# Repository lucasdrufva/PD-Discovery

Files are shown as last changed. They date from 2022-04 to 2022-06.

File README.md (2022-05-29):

# PD-Discovery

<div>
  <p align="center">
     
  </p>
</div>

A tool for analyzing and discovering the Power Delivery Protocol for USB-C

[Demo Video](https://youtu.be/lnGGlh1nLXM)

<p float="left">
  
   
</p>

Capable of 
 - Requesting identity from electronically marked cables, displaying supported Amp rating and length of cable
 - Displaying source capabilities including the different voltage and current ratings
 - Requesting power from a source and providing it on a screw terminal 
 - Displaying sink capabilities including the different voltage and current ratings
 - Providing power from internal battery to answer source request
 - Charge internal battery by requesting 5 Volt

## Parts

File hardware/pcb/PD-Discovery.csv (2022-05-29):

Reference | Quantity | Value | Footprint | Datasheet | MANUFACTURER | MAXIMUM_PACKAGE_HEIGHT | PARTREV | STANDARD
B1 | 1 | SSSS810701 | SSSS810701:SSSS810701
C11 C12 | 2 | 16pF | Capacitor_SMD:C_0603_1608Metric | ~
C13 | 1 | 1uF | Capacitor_SMD:C_0805_2012Metric | ~
C2 C5 C14 C15 C19 | 5 | 10uF | Capacitor_SMD:C_0603_1608Metric | ~
C20 C21 | 2 | 4.7uF | Capacitor_SMD:C_0603_1608Metric | ~
C4 C6 | 2 | 470pF | Capacitor_SMD:C_0603_1608Metric | ~
C1 C3 C7 C17 C18 | 5 | 0.1uF | Capacitor_SMD:C_0603_1608Metric | ~
C8 C9 C10 C16 | 4 | 22uF | Capacitor_SMD:C_0805_2012Metric | ~
D3 D5 | 2 | D_Schottky | digikey-footprints:DO-214AC | ~
D4 | 1 | LED | LED_SMD:LED_1206_3216Metric | ~
J1 | 1 | USB_C_Receptacle | Connector_USB:USB_C_Receptacle_Amphenol_12401610E4-2A | https://www.usb.org/sites/default/files/documents/usb_type-c.zip
J2 | 1 | Battery | Connector_JST:JST_PH_S2B-PH-K_1x02_P2.00mm_Horizontal | ~
J3 | 1 | SWD | Connector_PinHeader_2.54mm:PinHeader_1x04_P2.54mm_Vertical | ~
J4 | 1 | ScrewTerminal | 2pScrewTerminal:691214110002
J5 | 1 | DisplayFPC | ER-CON24HT:ER-CON24HT-1
L1 L2 | 2 | 22uH | Inductor_SMD:L_Sumida_CDMC6D28_7.25x6.5mm | ~
Q1 Q4 | 2 | AO3401A | Package_TO_SOT_SMD:SOT-23 | http://www.aosmd.com/pdfs/datasheet/AO3401A.pdf
Q2 Q3 Q5 Q6 | 4 | BC817 | Package_TO_SOT_SMD:SOT-23 | https://www.onsemi.com/pub/Collateral/BC818-D.pdf
Q7 | 1 | FS8205 | FS8205:SOT95P280X145-6N |  | Fortune | 1.45mm | 1.9 | IPC-7351B
R2 R10 | 2 | 1M | Resistor_SMD:R_0805_2012Metric | ~
R11 | 1 | 150K | Resistor_SMD:R_0805_2012Metric | ~
R12 | 1 | 100 | Resistor_SMD:R_0805_2012Metric | ~
R13 | 1 | 7.5K | Resistor_SMD:R_0805_2012Metric | ~
R16 | 1 | 1.35K | Resistor_SMD:R_0603_1608Metric | ~
R1 R15 R18 R21 R26 R27 R29 R30 R31 R32 R33 R34 | 12 | 10K | Resistor_SMD:R_0603_1608Metric | ~
R19 | 1 | 220 | Resistor_SMD:R_1206_3216Metric | ~
R22 | 1 | 1.5K | Resistor_SMD:R_0603_1608Metric | ~
R24 | 1 | 2K | Resistor_SMD:R_0603_1608Metric | ~
R28 | 1 | 900K | Resistor_SMD:R_0603_1608Metric | ~
R3 | 1 | 523K | Resistor_SMD:R_0603_1608Metric | ~
R4 R20 R23 R25 | 4 | 5K | Resistor_SMD:R_0603_1608Metric | ~
R5 R6 R7 | 3 | 4.7K | Resistor_SMD:R_0603_1608Metric | ~
R8 | 1 | 3K | Resistor_SMD:R_0805_2012Metric | ~
R9 R14 R17 | 3 | 1K | Resistor_SMD:R_0805_2012Metric | ~
S1 | 1 | SLLB120300 | SLLB120300:SW_SLLB120300 |  | ALPS | 3.5 mm |  | Manufacturer recommendations
SW3 | 1 | SW_Push | Button_Switch_SMD:SW_Push_1P1T_NO_6x6mm_H9.5mm | ~
U1 | 1 | TP4056 | TP40:SOIC127P600X175-9N
U2 | 1 | FUSB302BMPX | Package_DFN_QFN:WQFN-14-1EP_2.5x2.5mm_P0.5mm_EP1.45x1.45mm | http://www.onsemi.com/pub/Collateral/FUSB302B-D.PDF
U3 | 1 | DW01 | Package_TO_SOT_SMD:SOT-23-6
U4 U5 | 2 | MT3608 | Package_TO_SOT_SMD:SOT-23-6 | https://www.olimex.com/Products/Breadboarding/BB-PWR-3608/resources/MT3608.pdf
U6 | 1 | AMS1117-3.3 | Package_TO_SOT_SMD:SOT-223-3_TabPin2 | http://www.advanced-monolithic.com/pdf/ds1117.pdf
U7 | 1 | ATSAMD21E18A-A | Package_QFP:TQFP-32_7x7mm_P0.8mm | http://ww1.microchip.com/downloads/en/DeviceDoc/SAM_D21_DA1_Family_Data%20Sheet_DS40001882E.pdf
Y1 | 1 | Crystal | Crystal:Crystal_SMD_3215-2Pin_3.2x1.5mm | ~

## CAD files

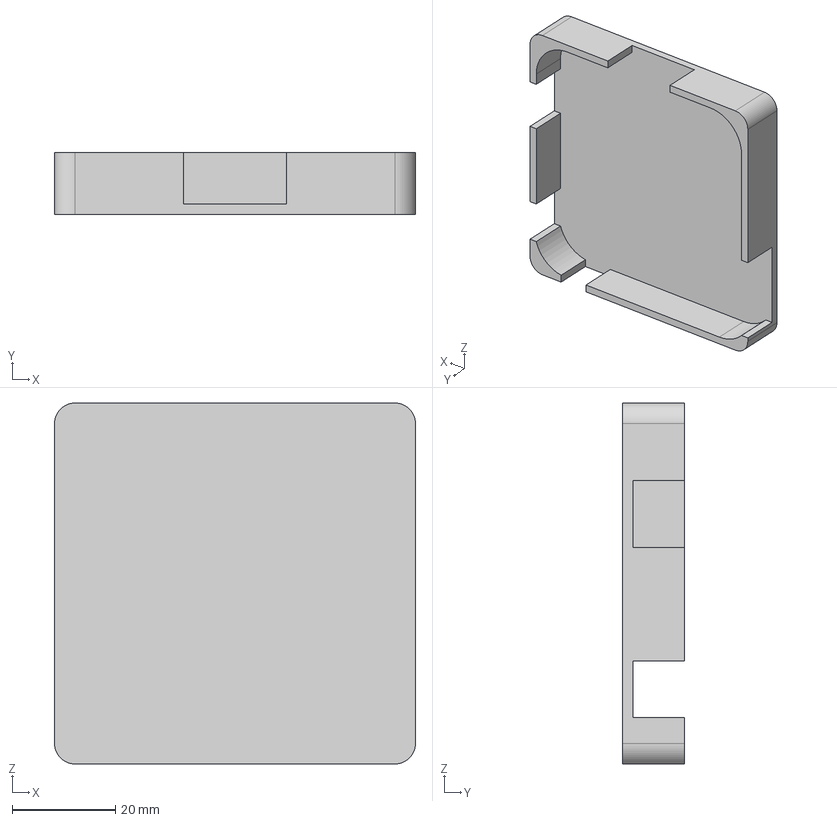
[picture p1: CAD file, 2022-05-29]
hardware/backpanel.step
70.0 x 12.0 x 70.0 mm

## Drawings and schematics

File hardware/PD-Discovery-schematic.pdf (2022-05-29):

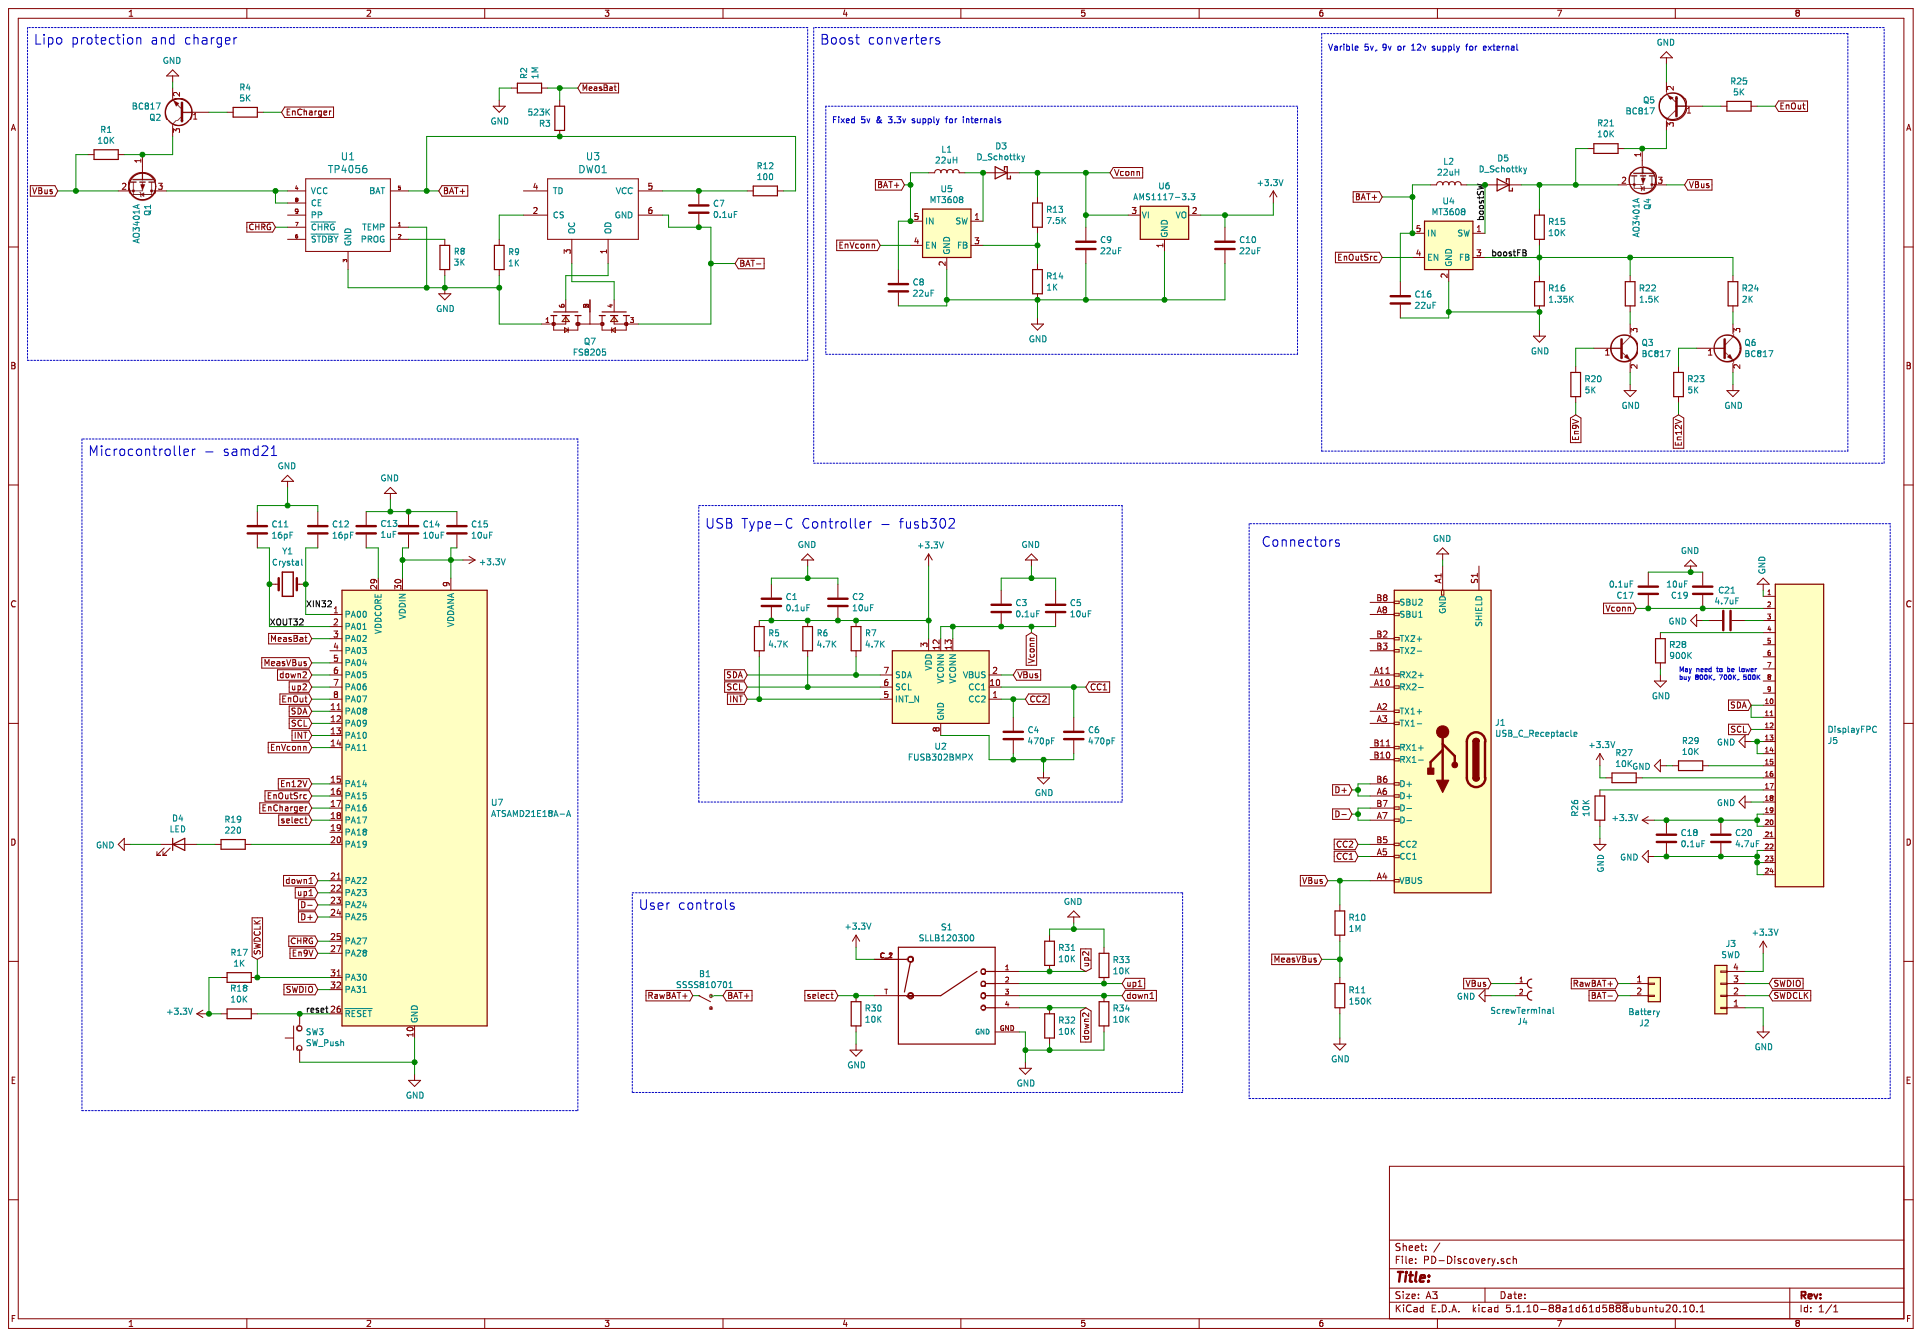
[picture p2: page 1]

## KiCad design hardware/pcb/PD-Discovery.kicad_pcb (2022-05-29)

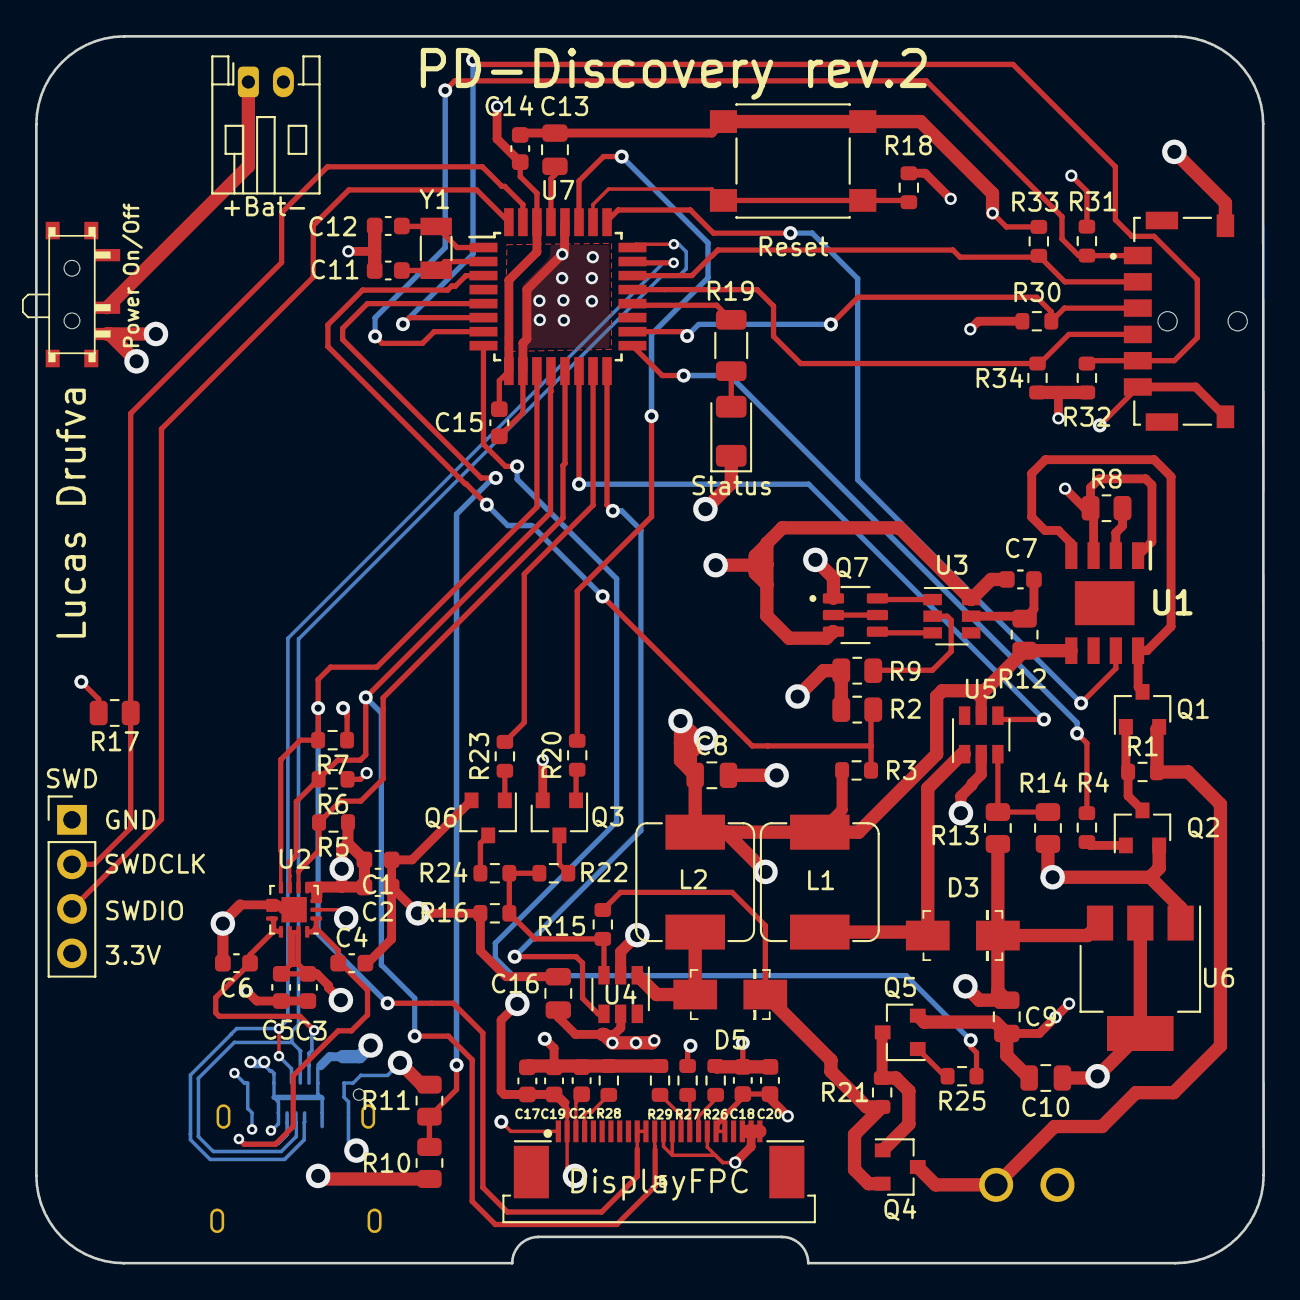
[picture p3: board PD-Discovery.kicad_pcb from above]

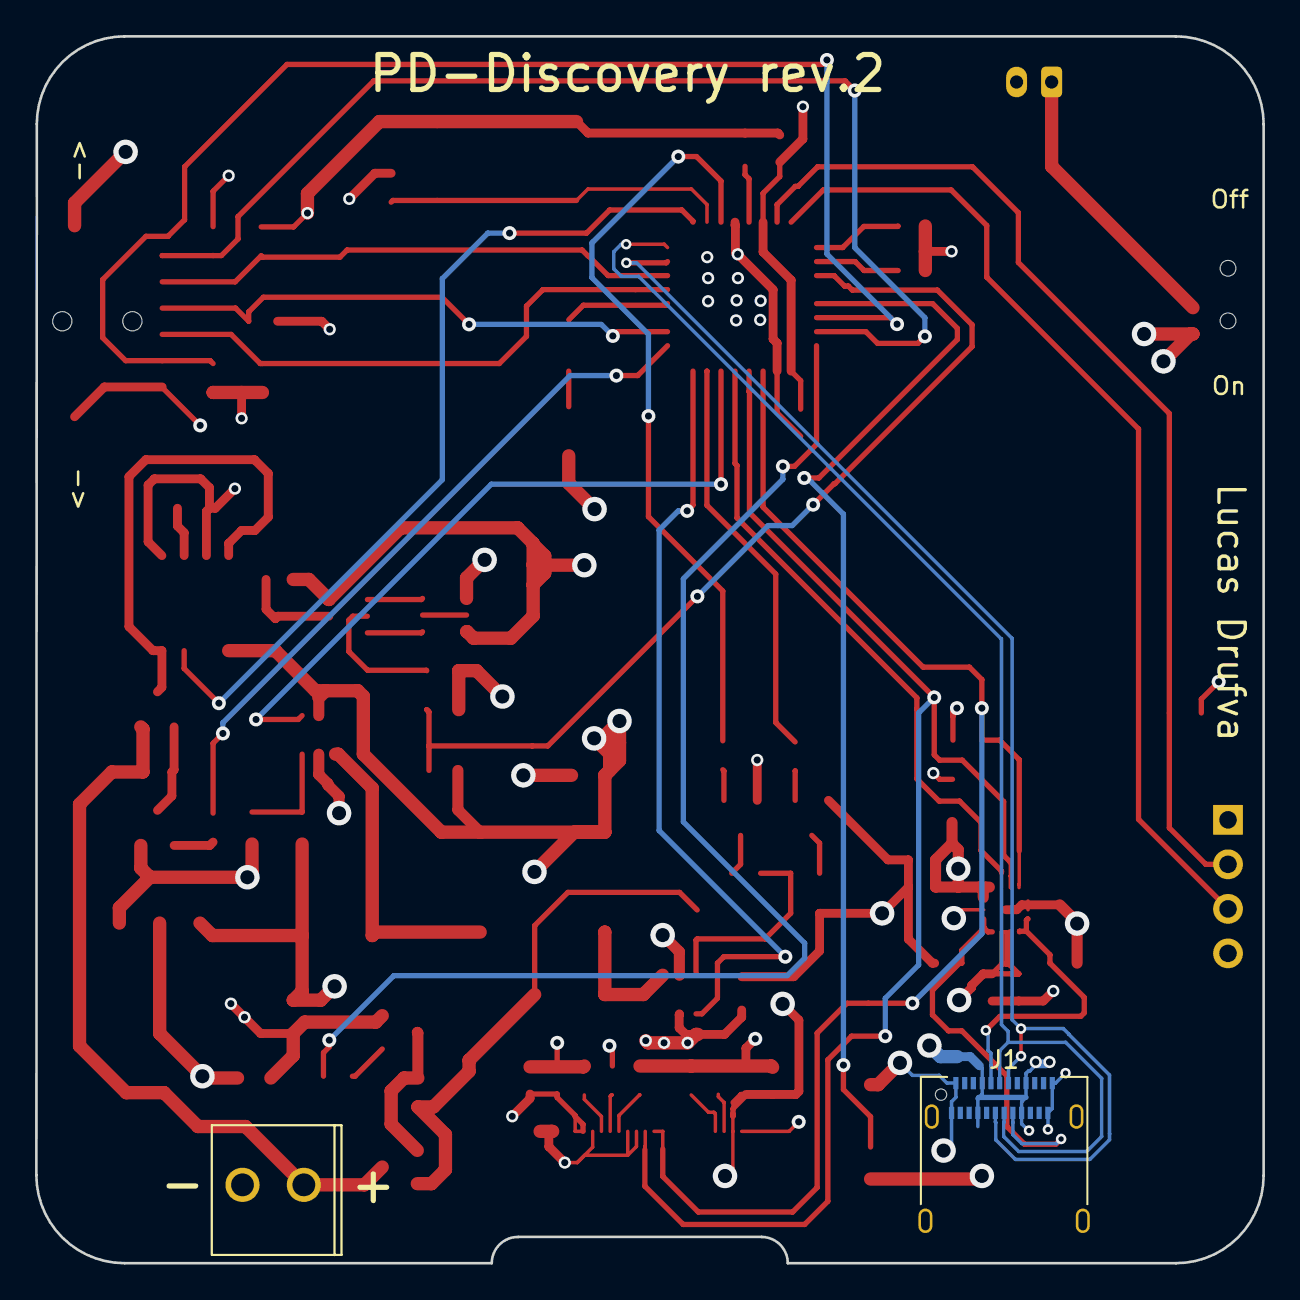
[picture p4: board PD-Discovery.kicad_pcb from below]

Board: 4 copper layers, 70.0 x 70.0 mm, 83 parts (2 on the bottom side), 61 nets.

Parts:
+Bat-: Battery; JST_PH_S2B-PH-K_1x02_P2.00mm_Horizontal
C1, C3, C7, C17, C18: 0.1uF; C_0603_1608Metric
C2, C5, C14, C15, C19: 10uF; C_0603_1608Metric
C4, C6: 470pF; C_0603_1608Metric
C8, C9, C10, C16: 22uF; C_0805_2012Metric
C11, C12: 16pF; C_0603_1608Metric
C13: 1uF; C_0805_2012Metric
C20, C21: 4.7uF; C_0603_1608Metric
D3, D5: D_Schottky; DO-214AC
J1: USB_C_Receptacle; USB_C_Receptacle_Amphenol_12401610E4-2A
J4: ScrewTerminal; 691214110002
J5: DisplayFPC; ER-CON24HT-1
L1, L2: 22uH; L_Sumida_CDMC6D28_7.25x6.5mm
Power On/Off: SSSS810701
Q1, Q4: AO3401A; SOT-23
Q2, Q3, Q5, Q6: BC817; SOT-23
Q7: FS8205; SOT95P280X145-6N
R1, R15, R18, R21, R26, R27, R29, R30, R31, R32, R33, R34: 10K; R_0603_1608Metric
R2, R10: 1M; R_0805_2012Metric
R3: 523K; R_0603_1608Metric
R4, R20, R23, R25: 5K; R_0603_1608Metric
R5, R6, R7: 4.7K; R_0603_1608Metric
R8: 3K; R_0805_2012Metric
R9, R14, R17: 1K; R_0805_2012Metric
R11: 150K; R_0805_2012Metric
R12: 100; R_0805_2012Metric
R13: 7.5K; R_0805_2012Metric
R16: 1.35K; R_0603_1608Metric
R19: 220; R_1206_3216Metric
R22: 1.5K; R_0603_1608Metric
R24: 2K; R_0603_1608Metric
R28: 900K; R_0603_1608Metric
Reset: SW_Push; SW_Push_1P1T_NO_6x6mm_H9.5mm
S1: SLLB120300; SW_SLLB120300
SWD: SWD; PinHeader_1x04_P2.54mm_Vertical
Status: LED; LED_1206_3216Metric
U1: TP4056; SOIC127P600X175-9N
U2: FUSB302BMPX; WQFN-14-1EP_2.5x2.5mm_P0.5mm_EP1.45x1.45mm
U3: DW01; SOT-23-6
U4, U5: MT3608; SOT-23-6
U6: AMS1117-3.3; SOT-223-3_TabPin2
U7: ATSAMD21E18A-A; TQFP-32_7x7mm_P0.8mm
Y1: Crystal; Crystal_SMD_3215-2Pin_3.2x1.5mm

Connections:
+3V3: C1.2, C2.2, C10.1, C14.2, C15.2, C18.1, C20.1, J5.19, J5.20, R5.1, R6.1, R7.1, R17.2, R18.1, R27.2, S1.C_1, S1.C_2, SWD.4, U2.3, U2.4, U6.2, U7.9, U7.30
/XIN32: C12.2, U7.1, Y1.1
/XOUT32: C11.2, U7.2, Y1.2
/boostFB: R15.2, R16.1, R22.1, R24.1, U4.3
/boostSW: D5.A, L2.2, U4.1
/reset: R18.2, Reset.2, U7.26
BAT+: C8.1, C16.1, L1.1, L2.1, Power On/Off.3, R3.1, R12.1, U1.5, U4.5, U5.5
BAT-: +Bat-.2, C7.2, Q7.3, U3.6
CC1: C6.1, J1.A5, U2.10, U2.11
CC2: C4.1, J1.B5, U2.1, U2.14
CHRG: U1.7, U7.25
D+: J1.A6, J1.B6, U7.24
D-: J1.A7, J1.B7, U7.23
En9V: R20.2, U7.27
En12V: R23.2, U7.15
EnCharger: R4.1, U7.17
EnOut: R25.1, U7.8
EnOutSrc: U4.4, U7.16
EnVconn: U5.4, U7.14
GND: C1.1, C2.1, C3.1, C4.2, C5.1, C6.2, C8.2, C9.2, C10.2, C11.1, C12.1, C13.2, C14.1, C15.1, C16.2, C17.2, C18.2, C19.2, C20.2, C21.2, J1.A1, J1.A12, J1.B1, J1.B12, J4.2, J5.1, J5.13, J5.14, J5.18, J5.22, J5.23, J5.24, Q2.2, Q3.2, Q5.2, Q6.2, Q7.1, R2.1, R8.1, R9.2, R11.2, R14.2, R16.2, R26.2, R28.1, R29.2, R30.2, R31.1, R32.2, R33.1, R34.2, Reset.1, S1.GND, SWD.1, Status.1, U1.1, U1.3, U2.8, U2.9, U2.15, U4.2, U5.2, U6.1, U7.10, U7.28
INT: R5.2, U2.5, U7.13
MeasBat: R2.2, R3.2, U7.3
MeasVBus: R10.2, R11.1, U7.5
unnamed: C7.1, R12.2, U3.5
unnamed: C13.1, U7.29
unnamed: C21.1, J5.3
unnamed: D3.A, L1.2, U5.1
unnamed: R19.2, Status.2
unnamed: D5.K, Q4.2, R15.1, R21.1
unnamed: J5.4, R28.2
unnamed: J5.15, R29.1
unnamed: J5.16, R27.1
unnamed: J5.17, R26.1
unnamed: Q1.1, Q2.3, R1.1
unnamed: Q1.3, U1.4, U1.8
unnamed: Q2.1, R4.2
unnamed: Q3.1, R20.1
unnamed: Q3.3, R22.2
unnamed: Q4.1, Q5.3, R21.2
unnamed: Q5.1, R25.2
unnamed: Q6.1, R23.1
unnamed: Q6.3, R24.2
unnamed: Q7.2, Q7.5
unnamed: Q7.4, U3.3
unnamed: Q7.6, U3.1
unnamed: R8.2, U1.2
unnamed: R9.1, U3.2
unnamed: R13.2, R14.1, U5.3
unnamed: R19.1, U7.20
RawBAT+: +Bat-.1, Power On/Off.2
SCL: J5.12, R6.2, U2.6, U7.12
SDA: J5.10, J5.11, R7.2, U2.7, U7.11
SWDCLK: R17.1, SWD.2, U7.31
SWDIO: SWD.3, U7.32
VBus: J1.A4, J1.A9, J1.B4, J1.B9, J4.1, Q1.2, Q4.3, R1.2, R10.1, U2.2
Vconn: C3.2, C5.2, C9.1, C17.1, C19.1, D3.K, J5.2, R13.1, U2.12, U2.13, U6.3
down1: R34.1, S1.3, U7.21
down2: R32.1, S1.4, U7.6
select: R30.1, S1.T, U7.18
up1: R33.2, S1.2, U7.22
up2: R31.2, S1.1, U7.7

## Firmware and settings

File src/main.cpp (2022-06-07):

#include <Arduino.h>

#include <Wire.h>
#include <stdlib.h>

#include "fusb302.h"
#include "oldtcpm.h"
#include "USB-PD.h"
#include "display.h"
#include "menu.h"
#include "buttons.h"
#include "pin-definitions.h"
#include "bsp.h"

Display display;

FUSB302 fusb;
extern PD_Engine pd;

volatile bool interruptFlag = false;
void isr()
{
  interruptFlag = true;
}

// Forward declaration
void main_menu();

void sinkCapRecieved(PD::Capabilities cap)
{
  display.drawPS(cap);
  button_register_cb(PIN_SELECT, SHORT, *main_menu);
}

void analyzeSink()
{
  pd.registerCapCB(*sinkCapRecieved);
  pinMode(PIN_ENABLE_VCONN, OUTPUT);
  digitalWrite(PIN_ENABLE_VCONN, HIGH);
  fusb.setIsSource(true);
  delay(100);

  while (true)
  {
    display.drawWaitConnection();
    if ((fusb.getConnection() & TCPM_DETECTION_RD))
    {
      break;
    }
  }

  delay(20);

  // Every source that provides power must support vSave5V, see USB PD rev2.0 6.4.1.2.3
  PD::PDO::PDO baseDataObject;
  baseDataObject.type = PD::PDO::Types::SOURCE_FIXED;
  baseDataObject.sourceFixed.voltage = 5000;
  baseDataObject.sourceFixed.current = 100;
  baseDataObject.sourceFixed.unconstrained = false;

  PD::Capabilities sourceCap;
  sourceCap.dataObjects[0] = baseDataObject;
  sourceCap.length = 1;

  // Sources must announce capapabilities on new connection
  pd.sendSourceCap(sourceCap);

  delay(100);

  pd.requestSinkCap(*sinkCapRecieved);
}

// Forward declaration
void sourceCapRecieved(PD::Capabilities cap);

int selected_pdo = -1;

void handlePDO0()
{
  selected_pdo = 0;
  pd.requestSourceCap(*sourceCapRecieved);
}
void handlePDO1() 
{ 
  selected_pdo = 1;
  pd.requestSourceCap(*sourceCapRecieved);
}
void handlePDO2()
{ 
  selected_pdo = 2;
  pd.requestSourceCap(*sourceCapRecieved);
}
void handlePDO3()
{ 
  selected_pdo = 3;
  pd.requestSourceCap(*sourceCapRecieved);
}
void handlePDO4()
{ 
  selected_pdo = 4;
  pd.requestSourceCap(*sourceCapRecieved);
}
void handlePDO5()
{ 
  selected_pdo = 5;
  pd.requestSourceCap(*sourceCapRecieved);
}
void handlePDO6()
{ 
  selected_pdo = 6;
  pd.requestSourceCap(*sourceCapRecieved);
}
void handlePDO7()
{ 
  selected_pdo = 7;
  pd.requestSourceCap(*sourceCapRecieved);
}

void (*handlePDO[8])() = {
    *handlePDO0,
    *handlePDO1,
    *handlePDO2,
    *handlePDO3,
    *handlePDO4,
    *handlePDO5,
    *handlePDO6,
    *handlePDO7,
};

// TODO refactor size constant to max PDO constant
Menu_item psMenuItems[9];

void sourceCapRecieved(PD::Capabilities cap)
{
  if( selected_pdo < 0){
    char titles[8][13];
    for (int i = 0; i < cap.length; i++)
    {
      // TODO support other types than source fixed
      PD::PDO::SourceFixed data = cap.dataObjects[i].sourceFixed;
      // TODO change from mA to A
      sprintf(titles[i], "%dV - %dmA", data.voltage / 1000, data.current);
      psMenuItems[i] = {.title = titles[i], .fn_ptr = handlePDO[i]};
    }
    psMenuItems[cap.length] = {.title = "Back", .fn_ptr = *main_menu};
    start_menu(psMenuItems, cap.length + 1);
  }
  else{
    pd.requestPower(selected_pdo);
    display.debug();
  }
}

void analyzeSource()
{
  fusb.setIsSource(false);

  while (true)
  {
    display.drawWaitConnection();
    if ((fusb.getConnection() & TCPM_DETECTION_RP))
    {
      break;
    }
  }

  pd.requestSourceCap(*sourceCapRecieved);
}

void identityRecieved(PD::Identity id)
{
  display.drawCable(id);
  button_register_cb(PIN_SELECT, SHORT, *main_menu);
}

void analyzeCable()
{
  pinMode(PIN_ENABLE_VCONN, OUTPUT);
  digitalWrite(PIN_ENABLE_VCONN, HIGH);
  fusb.setIsSource(true);
  delay(100);

  while (true)
  {
    display.drawWaitConnection();
    if ((fusb.getConnection() & TCPM_DETECTION_RA))
    {
      break;
    }
  }

  delay(500);

  pd.requestIdentity(PD::Destination::SOP_PRIME, *identityRecieved);
}

#define MAIN_MENU_SIZE 3
Menu_item MAIN_MENU_ITEMS[MAIN_MENU_SIZE] = {
    {.title = "Analyze Cable", .fn_ptr = *analyzeCable},
    {.title = "Analyze Source", .fn_ptr = *analyzeSource},
    {.title = "Analyze Sink", .fn_ptr = *analyzeSink},
};
void main_menu()
{
  pd.reset();
  start_menu(MAIN_MENU_ITEMS, MAIN_MENU_SIZE);
}

void setup()
{
  Wire.begin();
  display.begin();

  setup_buttons();

  // configure FUSB external interrupt
  attachInterrupt(2, isr, FALLING);

  pd.begin(&fusb);

  main_menu();
  button_register_cb(PIN_SELECT, LONG, *main_menu);
}

void loop()
{
  if (interruptFlag)
  {
    fusb.handleInterrupt();
    interruptFlag = false;
  }

  run_buttons();
}

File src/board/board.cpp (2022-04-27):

#include "board/board.h"

uint16_t Board::readVbusMilliVolt(){
    int raw = analogRead(A3);
    int voltage = (((raw*1000) / 1024) * 22 );
    return (uint16_t) voltage;
}

uint16_t Board::readBatteryMilliVolt(){
    int raw = analogRead(A0);
    int voltage = (((raw*1000) / 1024) * 631 ) / 100;
    return (uint16_t) voltage;
}

//TODO init pins
void Board::enableOutputSrc(){
    pinMode(29, OUTPUT);
    digitalWrite(29, HIGH);
}

void Board::disableOutputSrc(){
    pinMode(29, OUTPUT);
    digitalWrite(29, LOW);
}

void Board::enableOutputVoltage(){
    pinMode(21, OUTPUT);
    digitalWrite(21, HIGH);
}

void Board::disableOutputVoltage(){
    pinMode(21, OUTPUT);
    digitalWrite(21, LOW);
}

void Board::setOutputSrc5v(){
    pinMode(31, OUTPUT);
    pinMode(28, OUTPUT);
    digitalWrite(31, LOW);
    digitalWrite(28, LOW);
}

void Board::setOutputSrc9v(){
    digitalWrite(31, HIGH);
    digitalWrite(28, LOW);
}

void Board::setOutputSrc12v(){
    digitalWrite(31, HIGH);
    digitalWrite(28, HIGH);
}

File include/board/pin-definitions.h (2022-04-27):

#pragma once
#define PIN_ENABLE_CHARGING 8
#define PIN_MEASURE_VBUS A4
#define PIN_FUSB_INTERRUPT 2

#define PIN_UP_2 20
#define PIN_UP_1 1
#define PIN_DOWN_1 0
#define PIN_DOWN_2 19
#define PIN_SELECT 9
